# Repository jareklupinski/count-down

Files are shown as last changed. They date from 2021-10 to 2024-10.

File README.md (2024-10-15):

# count-down
A clock that counts down until your next meeting



(the photo makes the lights look blurrier than they are in real life, the LED numbers are very crisp to the human eye)

A Heroku App runs a Python script that downloads your Google Calendar and parses out the next appointment timestamp.

The count-down clock connects to the Heroku App and compares the next appoinment timestamp to the current time.

The clock then displays the hours and minutes or minutes and seconds until your next appointment.

board

schem

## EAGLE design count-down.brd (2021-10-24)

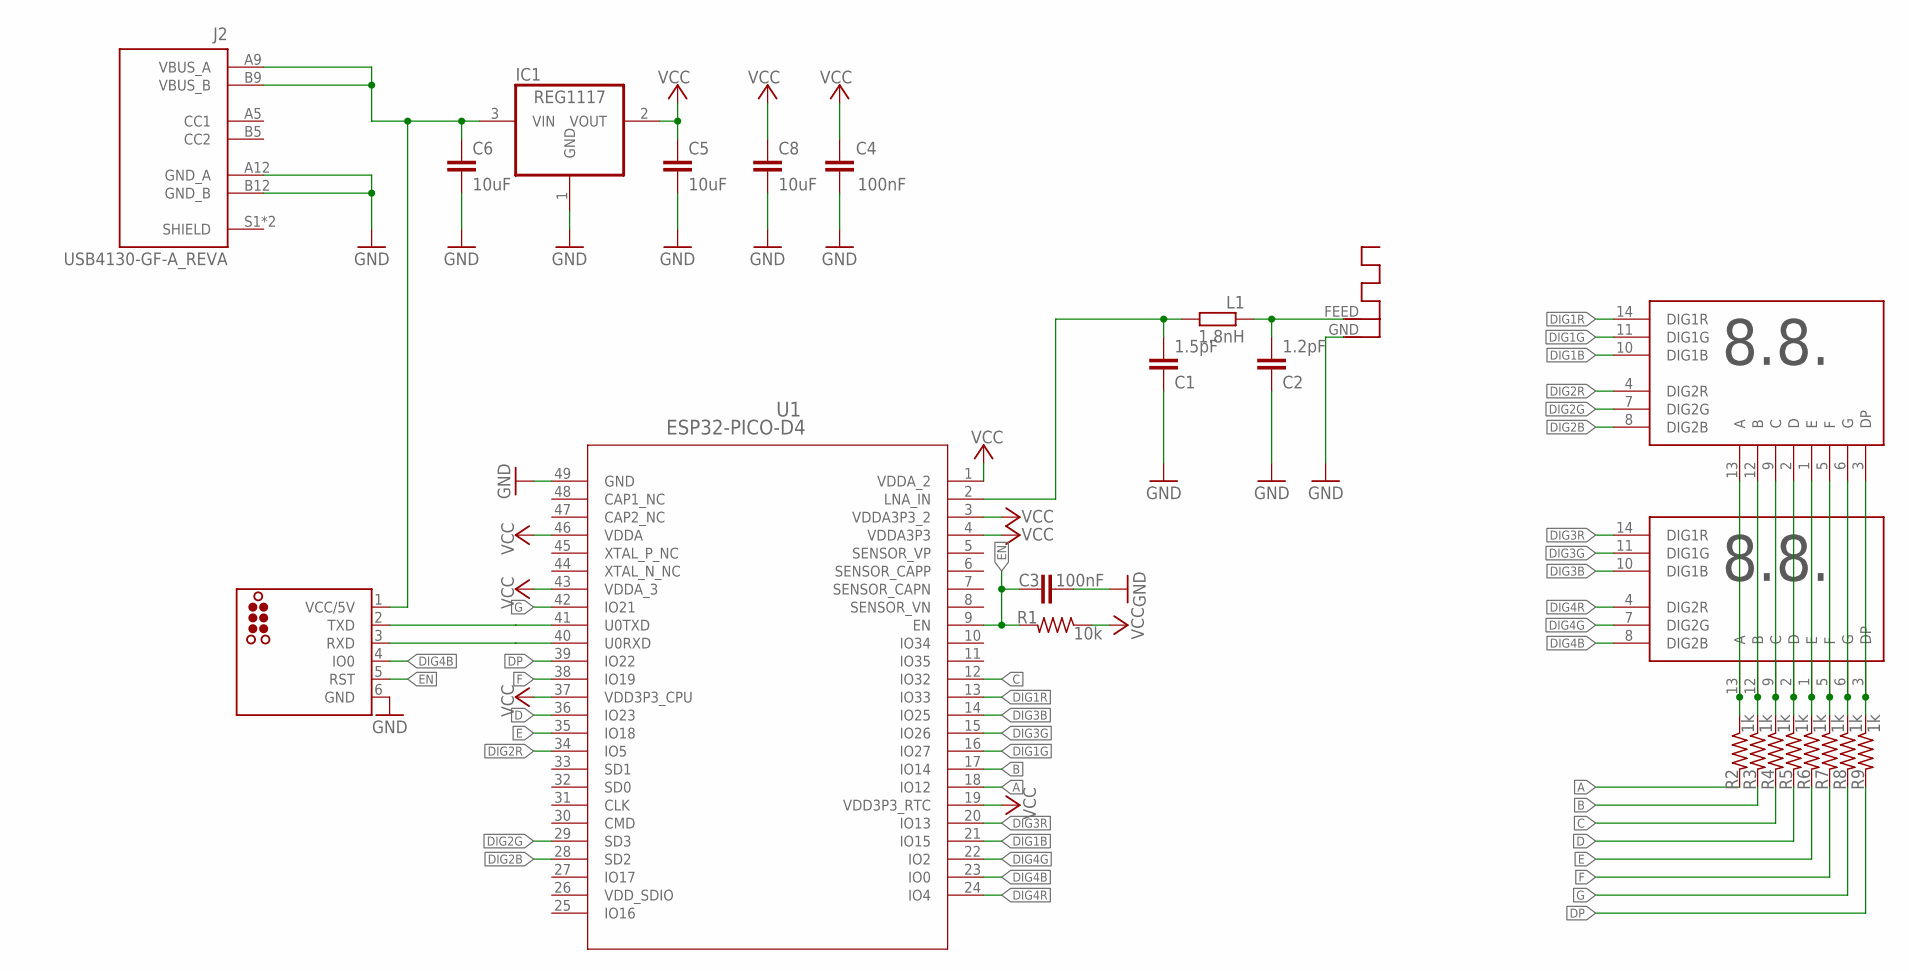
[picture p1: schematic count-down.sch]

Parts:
ANT1: ANTENNA; RN-ANT
C1: 1.5pF; C0402
C2: 1.2pF; C0402
C3, C4: 100nF; C0402
C5, C6, C8: 10uF; C0805
IC1: REG1117; SOT223
J2: USB4130-GF-A_REVA; GCT_USB4130-GF-A_REVA
L1: 1.8nH; R0402
LED1, LED2: ACD8143DIP; DIP14
R1: 10k; R0402
R2, R3, R4, R5, R6, R7, R8, R9: 1k; R0402
U1: ESP32-PICO-D4; ESP32-PICO-D4_EXP
U$1: TC2030-ESP; TC2030-MCP

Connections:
A: R2.2, U1.18 (IO12)
B: R3.2, U1.17 (IO14)
C: R4.2, U1.12 (IO32)
D: R5.2, U1.36 (IO23)
DIG1B: LED1.10 (DIG1B), U1.21 (IO15)
DIG1G: LED1.11 (DIG1G), U1.16 (IO27)
DIG1R: LED1.14 (DIG1R), U1.13 (IO33)
DIG2B: LED1.8 (DIG2B), U1.28 (SD2)
DIG2G: LED1.7 (DIG2G), U1.29 (SD3)
DIG2R: LED1.4 (DIG2R), U1.34 (IO5)
DIG3B: LED2.10 (DIG1B), U1.14 (IO25)
DIG3G: LED2.11 (DIG1G), U1.15 (IO26)
DIG3R: LED2.14 (DIG1R), U1.20 (IO13)
DIG4B: LED2.8 (DIG2B), U1.23 (IO0), U$1.4 (IO0)
DIG4G: LED2.7 (DIG2G), U1.22 (IO2)
DIG4R: LED2.4 (DIG2R), U1.24 (IO4)
DP: R9.2, U1.39 (IO22)
E: R6.2, U1.35 (IO18)
EN: C3.2, R1.2, U1.9 (EN), U$1.5 (RST)
F: R7.2, U1.38 (IO19)
G: R8.2, U1.42 (IO21)
GND: ANT1.GND, C1.1, C2.1, C3.1, C4.2, C5.2, C6.2, C8.2, IC1.1 (GND), J2.A12 (GND_A), J2.B12 (GND_B), U1.49 (GND), U$1.6 (GND)
unnamed: ANT1.FEED, C2.2, L1.1
unnamed: C1.2, L1.2, U1.2 (LNA_IN)
unnamed: LED1.13 (A), LED2.13 (A), R2.1
unnamed: LED1.12 (B), LED2.12 (B), R3.1
unnamed: LED1.9 (C), LED2.9 (C), R4.1
unnamed: LED1.2 (D), LED2.2 (D), R5.1
unnamed: LED1.1 (E), LED2.1 (E), R6.1
unnamed: LED1.5 (F), LED2.5 (F), R7.1
unnamed: LED1.6 (G), LED2.6 (G), R8.1
unnamed: LED1.3 (DP), LED2.3 (DP), R9.1
unnamed: C6.1, IC1.3 (VIN), J2.A9 (VBUS_A), J2.B9 (VBUS_B), U$1.1 (VCC/5V)
unnamed: U1.41 (U0TXD), U$1.2 (TXD)
unnamed: U1.40 (U0RXD), U$1.3 (RXD)
VCC: C4.1, C5.1, C8.1, IC1.2 (VOUT), R1.1, U1.1 (VDDA_2), U1.3 (VDDA3P3_2), U1.4 (VDDA3P3), U1.19 (VDD3P3_RTC), U1.37 (VDD3P3_CPU), U1.43 (VDDA_3), U1.46 (VDDA)
VDD_SDIO: U1.26 (VDD_SDIO)

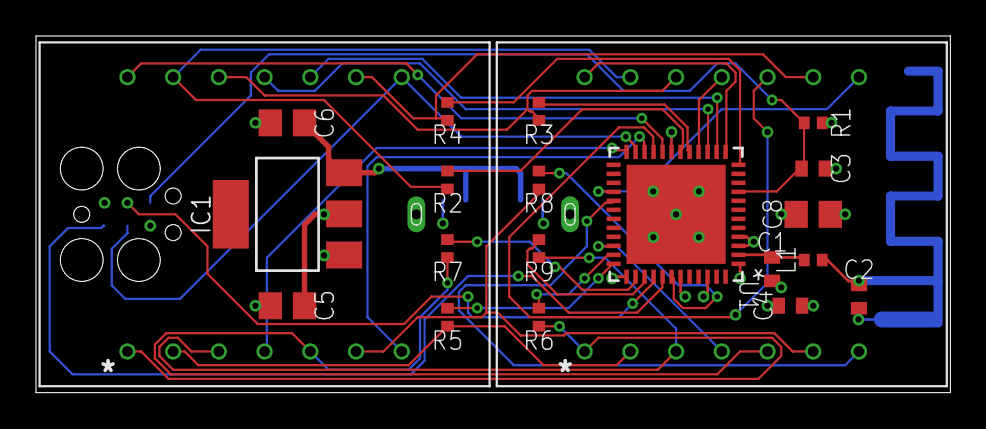
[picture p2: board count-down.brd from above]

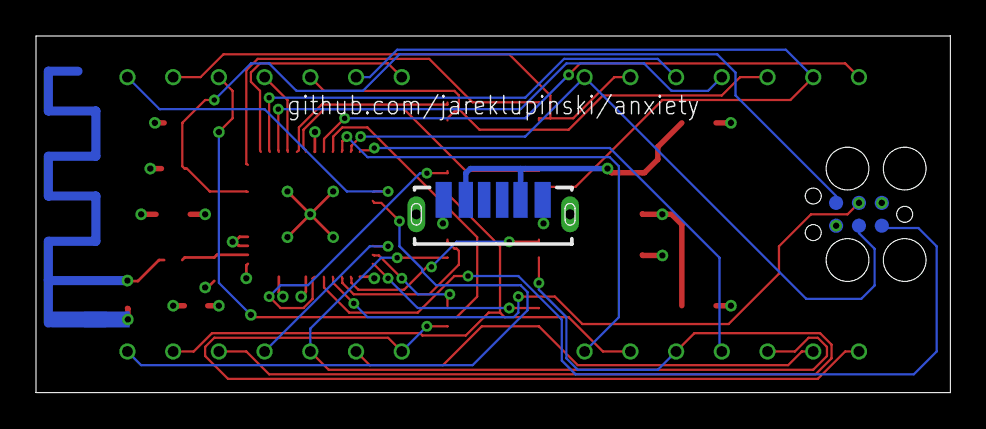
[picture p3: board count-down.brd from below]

Board: 4 copper layers, 50.8 x 19.8 mm, 24 parts (3 on the bottom side), 36 nets.

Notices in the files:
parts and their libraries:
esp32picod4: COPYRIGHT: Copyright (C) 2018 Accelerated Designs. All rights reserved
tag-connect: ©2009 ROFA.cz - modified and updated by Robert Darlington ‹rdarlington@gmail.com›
